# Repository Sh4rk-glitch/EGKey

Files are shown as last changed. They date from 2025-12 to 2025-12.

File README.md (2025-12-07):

# EGKey (ErgoKey)

A custom ergonomic keyboard PCB design using Choc-style hotswap sockets, a face-down Promicro footprint, and an optional OLED. This repository contains KiCad board sources, generated gerbers, mechanical DXF outlines, and footprint helper scripts driven by a YAML configuration.

---

# Files

## CAD
Inside `EGKey main file` there are many different files below is what is most important and how to get there: 
Starting off with the CAD files, the CAD is under `CAD files`. The main CAD file is `case. step`, if you want the other CAD files then click on `cases` and the rest are in there.
To see the outlines for the CAD go to `config.yaml` and then `output` and then `outlines`.

## PCBs
The PCBs are under `pcbs` then going to `ALL PCBS`. The main PCB file is `EGKeyMasterPCB`, if you wish to see the no routing and my previous attempts at routing then click on `EGKey-noRouting` and `EGKeyPCB-routingV2`.
The gerber file is under `pcbs` then click on the `EGKeyGerb` file, it's a zip file so it'll download as a zip.
Under `config.yaml` the footprint for the mounting hole is there under `footprints` and then its the only file under there.

## Firmware
To get to the firmware file, click on `firmware` which will be under `EGKey main file` and then inside `firmware` will be all the firmware writting for EGKey.

## Bill of Materials
  Part                                 Count                     Cost
- PCB Fab (With Shipping)	               1	                  $30.00 USD
- Arduino Pro Micro	                     1	                  $10.00 USD
- OLED Display	                         1	                   $4.00 USD
- Kailh Choc v2 Switches	               6 (58 Keys Total)	  $30.00 USD
- 1N4148 Diodes (SMD)	                   6 (58 Diodes Total)	 $2.00 USD
- Kailh Choc Hotswap Sockets	           6 (58 Sockets Total)	$10.00 USD
- Reset Switch (SMD, 4 Pin, Flat)	       1	                   $0.50 USD
- Mill Max Sockets & Pins	               1	                   $7.50 USD
- Medium Profile Controller Socket	     1	                   $0.50 USD
- Choc v1 Keycaps	                       1	                  $50-75 USD

Total: $140-160 USD

---
# Pictures:
## PCBs:


## CAD:


All images are located on my journal, at:
[https://blueprint.hackclub.com/projects/5019](url)

If you have any questions, email me at shouryamishra011@gmail.com

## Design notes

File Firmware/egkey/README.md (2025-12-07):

EGKey QMK scaffold
===================

This folder contains a minimal QMK keyboard scaffold for the EGKey PCB.

Important: This scaffold uses placeholder pin mappings. Replace `MATRIX_ROW_PINS` and
`MATRIX_COL_PINS` in `config.h` with the actual pins from your PCB before building.

Quick steps to build and flash (recommended: use WSL or QMK MSYS):

1. Copy this folder into your QMK firmware repo under `keyboards/egkey`:

   - `qmk_firmware/keyboards/egkey`

2. Install QMK build environment (see https://docs.qmk.fm)

3. From the qmk_firmware root (WSL / MSYS):

   ```powershell
   qmk compile -kb egkey -km default
   ```

4. To flash using QMK CLI (replace COM3 with your Pro Micro port):

   ```powershell
   qmk flash -kb egkey -km default -p COM3
   ```

Or use QMK Toolbox: build a `.hex` then open QMK Toolbox, put your Pro Micro into
bootloader (double-tap reset or short RST to GND), then load the hex and flash.

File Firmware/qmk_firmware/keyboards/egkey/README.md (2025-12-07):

EGKey QMK scaffold
===================

This folder contains a minimal QMK keyboard scaffold for the EGKey PCB.

Important: This scaffold uses conservative pin mappings to allow an initial
build. Verify `MATRIX_ROW_PINS` and `MATRIX_COL_PINS` in `config.h` against
your schematic and KiCad before using the board in production.

Quick steps to build and flash (recommended: use WSL or QMK MSYS):

1. From the qmk_firmware root (WSL / MSYS):

   ```bash
   qmk compile -kb egkey -km dm9records_ergoinu_layout_2025-12-07
   ```

2. To flash using QMK CLI (replace COM3 with your Pro Micro port):

   ```powershell
   qmk flash -kb egkey -km dm9records_ergoinu_layout_2025-12-07 -p COM3
   ```

Or use QMK Toolbox: build a `.hex` then open QMK Toolbox, put your Pro Micro into
bootloader (double-tap reset or short RST to GND), then load the hex and flash.

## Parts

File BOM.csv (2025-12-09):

Pro Micro (USB-C Version) - 5V/16MHz - Arduino-compatible ATmega32U4:
https://keeb.io/products/pro-micro-usb-c-version-5v-16mhz-arduino-compatible-atmega32u4
OLED Display:
https://kriscables.com/product/oled-display/
Kailh Box White Mechanical Keyboard Switches,3-Pin 45gf Clicky/Speed Typing/Gaming/Waterproof Switches(72Pcs,Kailh Box White):
https://www.amazon.com/Zjmehty-Mechanical-Keyboard-Switches-Waterproof/dp/B0CBPR6SVL?hvadid=648114561242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
1N4148 Diodes SMD (10 pcs):
https://www.aliexpress.us/item/3256806137153769.html?mp=1
Kailh Choc V1 Hot-swap Sockets (10 pcs):
https://holykeebs.com/products/kailh-choc-hotswap-sockets?variant=44532144079138
Reset Switch (SMD, 4 Pin, Flat):
https://42keebs.eu/shop/parts/components/reset-switch/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
Machine Sockets and pins:
https://typeractive.xyz/products/machine-sockets-and-pins?variant=45741664469223
Microcontroller Socket (Medium-profile, 40-pin):
https://42keebs.eu/shop/parts/components/microcontroller-socket-medium-profile/?attribute_pa_colour=black
CFX WoB Translucent Font Keycap Set:
https://keebd.com/en-us/products/cfx-wob-translucent-font-keycap-set

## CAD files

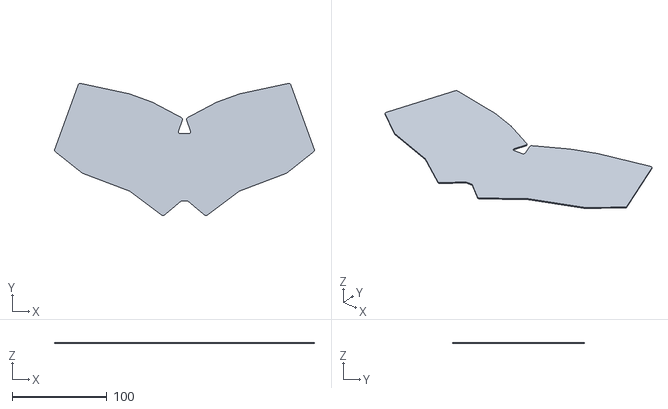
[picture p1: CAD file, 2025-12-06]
CAD Files/cases/xlBottom.stl
274.0 x 139.4 x 1.00

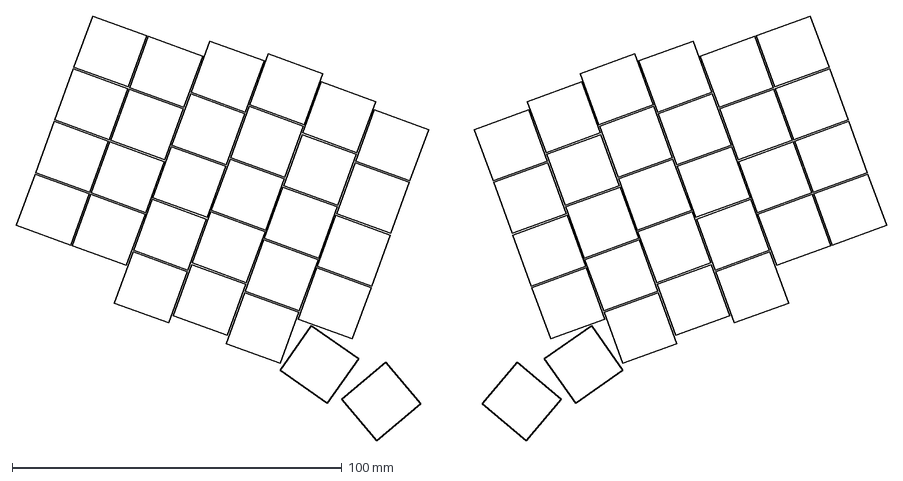
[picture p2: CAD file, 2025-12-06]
EGKey Main File/config.yaml/output/outlines/keys.dxf
263.8 x 128.8 mm

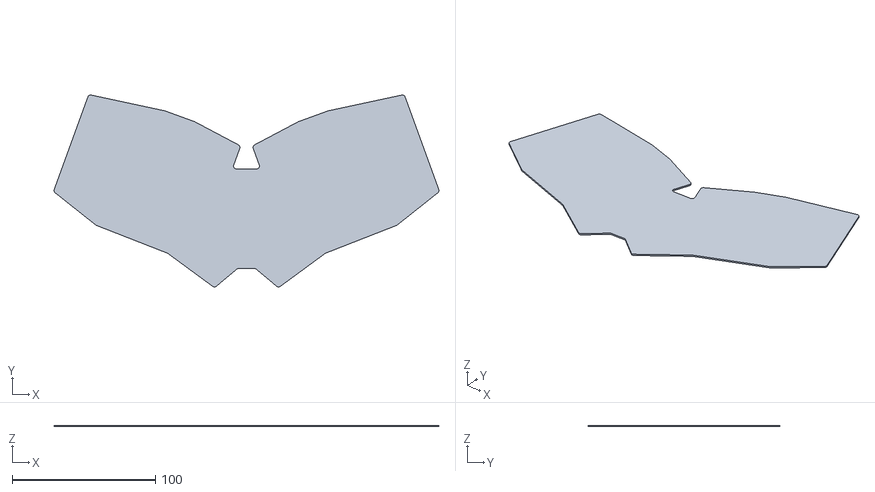
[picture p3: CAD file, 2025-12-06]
CAD Files/cases/bottom.stl
268.8 x 134.0 x 1.00

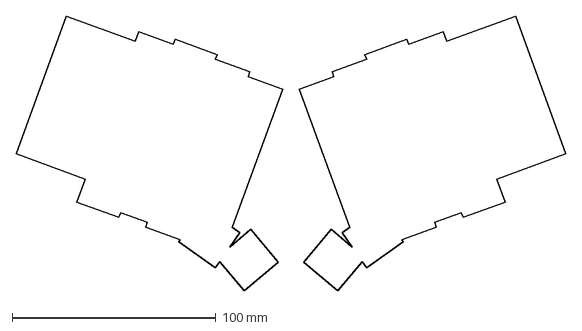
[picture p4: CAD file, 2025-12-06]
EGKey Main File/config.yaml/output/outlines/raw.dxf
269.6 x 134.8 mm

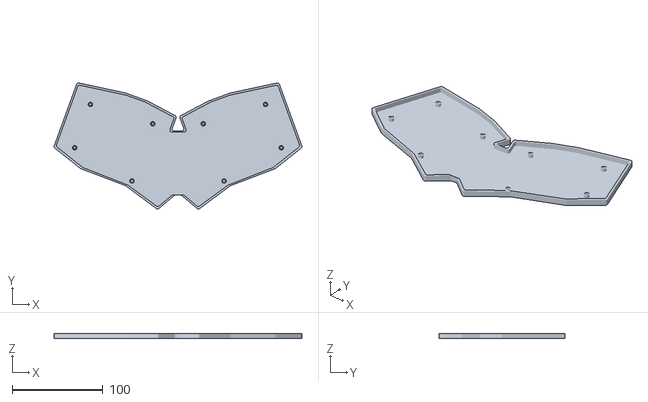
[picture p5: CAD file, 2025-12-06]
CAD Files/cases/case.stl
274.0 x 139.4 x 5.60

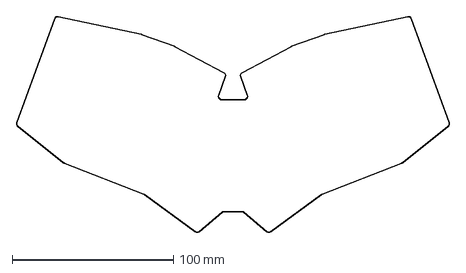
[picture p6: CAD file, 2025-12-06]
EGKey Main File/config.yaml/output/outlines/board.dxf
269.2 x 134.4 mm

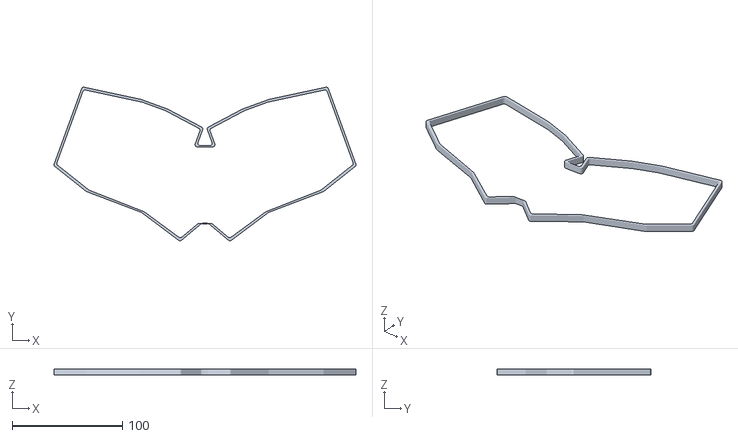
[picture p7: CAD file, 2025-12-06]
CAD Files/cases/wall.stl
274.0 x 139.4 x 5.60

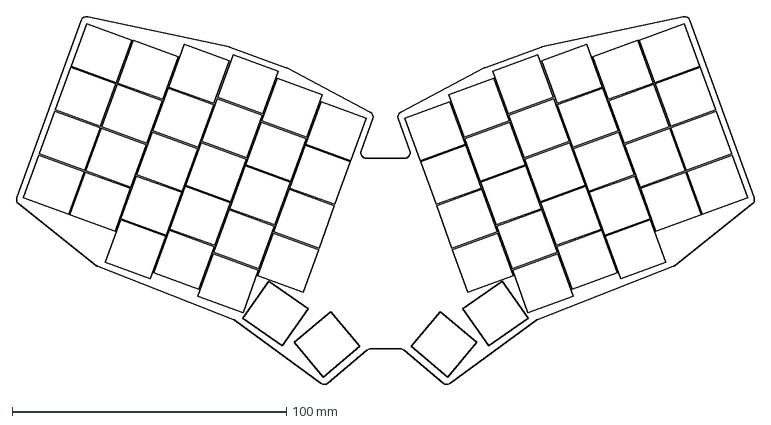
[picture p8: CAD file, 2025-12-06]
EGKey Main File/config.yaml/output/outlines/combo.dxf
269.2 x 134.4 mm

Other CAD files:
CAD Files/case.step

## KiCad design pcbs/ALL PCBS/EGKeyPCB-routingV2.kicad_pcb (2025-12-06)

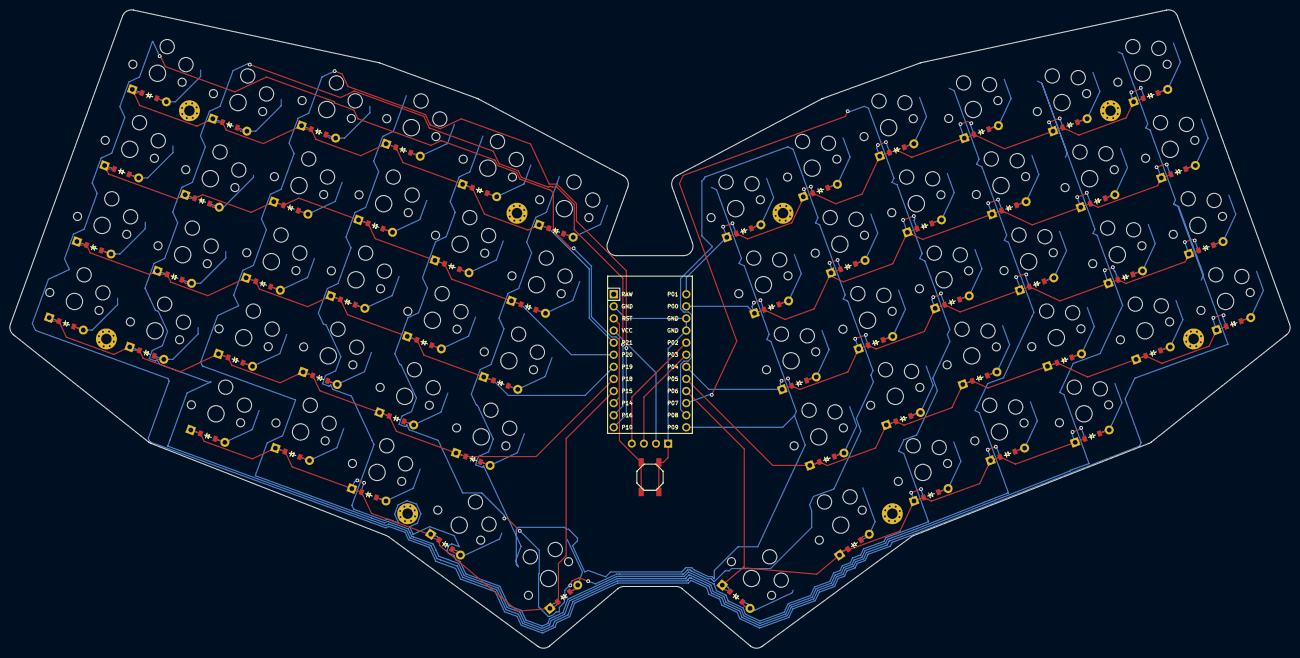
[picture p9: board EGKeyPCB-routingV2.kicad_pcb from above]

Board: 2 copper layers, 268.9 x 134.0 mm, 127 parts (0 on the bottom side), 79 nets.

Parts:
B1: SW_TACT_ALPS_SKQGABE010
D1, D2, D3, D4, D5, D6, D7, D8, D9, D10, D11, D12, D13, D14, D15, D16, D17, D18, D19, D20, D21, D22, D23, D24, D25, D26, D27, D28, D29, D30, D31, D32, D33, D34, D35, D36, D37, D38, D39, D40, D41, D42, D43, D44, D45, D46, D47, D48, D49, D50, D51, D52, D53, D54, D55, D56, D57, D58: ComboDiode
MCU1: ProMicro
OLED1: OLED; OLED_headers
S1, S2, S3, S4, S5, S6, S7, S8, S9, S10, S11, S12, S13, S14, S15, S16, S17, S18, S19, S20, S21, S22, S23, S24, S25, S26, S27, S28, S29, S30, S31, S32, S33, S34, S35, S36, S37, S38, S39, S40, S41, S42, S43, S44, S45, S46, S47, S48, S49, S50, S51, S52, S53, S54, S55, S56, S57, S58: PG1350
_1, _2, _3, _4, _5, _6, _7, _8: MountingHole_2.2mm_M2_Pad_Via

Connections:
GND: B1.1, MCU1.2, MCU1.15, MCU1.16, OLED1.1
P0: D32.1, D36.1, D41.1, D46.1, D51.1, D55.1, MCU1.14
P1: D33.1, D37.1, D42.1, D47.1, D52.1, D56.1, MCU1.13
P2: MCU1.17, OLED1.4
P3: MCU1.18, OLED1.3
P4: D31.1, D35.1, D40.1, D45.1, D50.1, D54.1, MCU1.19
P5: D30.1, D34.1, D39.1, D44.1, D49.1, D53.1, MCU1.20
P6: D38.1, D43.1, D48.1, D57.1, D58.1, MCU1.21
P7: MCU1.22, S15.1, S16.1, S17.1, S18.1, S19.1, S44.1, S45.1, S46.1, S47.1, S48.1
P8: MCU1.23, S20.1, S21.1, S22.1, S23.1, S28.1, S49.1, S50.1, S51.1, S52.1, S57.1
P9: MCU1.24, S24.1, S25.1, S26.1, S27.1, S29.1, S53.1, S54.1, S55.1, S56.1, S58.1
P10: MCU1.12, S10.1, S11.1, S12.1, S13.1, S14.1, S39.1, S40.1, S41.1, S42.1, S43.1
P14: MCU1.10, S1.1, S2.1, S3.1, S4.1, S30.1, S31.1, S32.1, S33.1
P15: D9.1, D14.1, D19.1, D28.1, D29.1, MCU1.9
P16: MCU1.11, S5.1, S6.1, S7.1, S8.1, S9.1, S34.1, S35.1, S36.1, S37.1, S38.1
P18: D1.1, D5.1, D10.1, D15.1, D20.1, D24.1, MCU1.8
P19: D2.1, D6.1, D11.1, D16.1, D21.1, D25.1, MCU1.7
P20: D3.1, D7.1, D12.1, D17.1, D22.1, D26.1, MCU1.6
P21: D4.1, D8.1, D13.1, D18.1, D23.1, D27.1, MCU1.5
RST: B1.2, MCU1.3
VCC: MCU1.4, OLED1.2
index_bottom: D20.2, S20.2
index_home: D21.2, S21.2
index_mod: D19.2, S19.2
index_num: D23.2, S23.2
index_top: D22.2, S22.2
inner_bottom: D24.2, S24.2
inner_home: D25.2, S25.2
inner_num: D27.2, S27.2
inner_top: D26.2, S26.2
layer_cluster: D28.2, S28.2
middle_bottom: D15.2, S15.2
middle_home: D16.2, S16.2
middle_mod: D14.2, S14.2
middle_num: D18.2, S18.2
middle_top: D17.2, S17.2
mirror_index_bottom: D49.2, S49.2
mirror_index_home: D50.2, S50.2
mirror_index_mod: D48.2, S48.2
mirror_index_num: D52.2, S52.2
mirror_index_top: D51.2, S51.2
mirror_inner_bottom: D53.2, S53.2
mirror_inner_home: D54.2, S54.2
mirror_inner_num: D56.2, S56.2
mirror_inner_top: D55.2, S55.2
mirror_layer_cluster: D57.2, S57.2
mirror_middle_bottom: D44.2, S44.2
mirror_middle_home: D45.2, S45.2
mirror_middle_mod: D43.2, S43.2
mirror_middle_num: D47.2, S47.2
mirror_middle_top: D46.2, S46.2
mirror_outer_bottom: D30.2, S30.2
mirror_outer_home: D31.2, S31.2
mirror_outer_num: D33.2, S33.2
mirror_outer_top: D32.2, S32.2
mirror_pinky_bottom: D34.2, S34.2
mirror_pinky_home: D35.2, S35.2
mirror_pinky_num: D37.2, S37.2
mirror_pinky_top: D36.2, S36.2
mirror_ring_bottom: D39.2, S39.2
mirror_ring_home: D40.2, S40.2
mirror_ring_mod: D38.2, S38.2
mirror_ring_num: D42.2, S42.2
mirror_ring_top: D41.2, S41.2
mirror_space_cluster: D58.2, S58.2
outer_bottom: D1.2, S1.2
outer_home: D2.2, S2.2
outer_num: D4.2, S4.2
outer_top: D3.2, S3.2
pinky_bottom: D5.2, S5.2
pinky_home: D6.2, S6.2
pinky_num: D8.2, S8.2
pinky_top: D7.2, S7.2
ring_bottom: D10.2, S10.2
ring_home: D11.2, S11.2
ring_mod: D9.2, S9.2
ring_num: D13.2, S13.2
ring_top: D12.2, S12.2
space_cluster: D29.2, S29.2

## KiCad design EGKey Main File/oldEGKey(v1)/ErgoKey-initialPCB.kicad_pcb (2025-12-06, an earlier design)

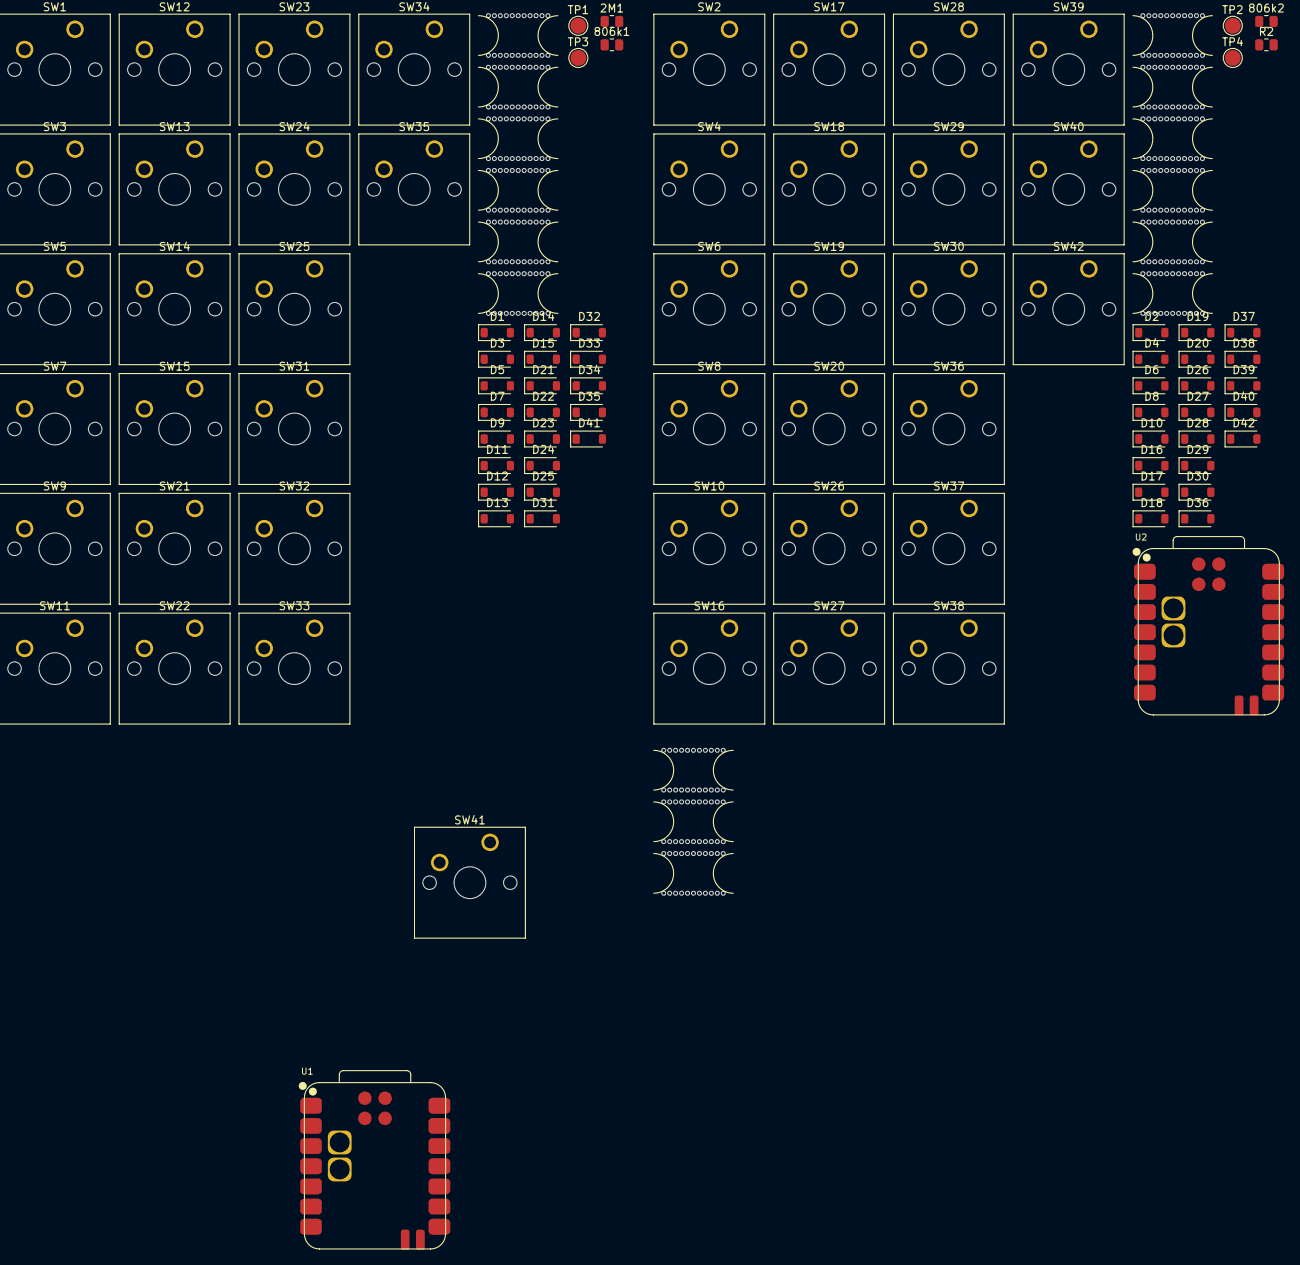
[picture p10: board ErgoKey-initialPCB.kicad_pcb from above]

Board: 2 copper layers, 109 parts (0 on the bottom side), 23 nets, no tracks yet.

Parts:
2M1, 806k2: R3; R_0805_2012Metric
806k1: R; R_0805_2012Metric
BO1, BO2, BO3: break off; mouse-bite-5mm-slot
D1, D2, D3, D4, D5, D6, D7, D8, D9, D10, D11, D12, D13, D14, D15, D16, D17, D18, D19, D20, D21, D22, D23, D24, D25, D26, D27, D28, D29, D30, D31, D32, D33, D34, D35, D36, D37, D38, D39, D40, D41, D42: D; D_SOD-123
H1, H2, H3, H4, H5, H6, H7, H8, H9, H10, H11, H12: mouse-bite-5mm-slot
R2: R; R_0805_2012Metric
SW1, SW2, SW3, SW4, SW5, SW6, SW7, SW8, SW9, SW10, SW11, SW12, SW13, SW14, SW15, SW16, SW17, SW18, SW19, SW20, SW21, SW22, SW23, SW24, SW25, SW26, SW27, SW28, SW29, SW30, SW31, SW32, SW33, SW34, SW35, SW36, SW37, SW38, SW39, SW40, SW41, SW42: SW_Push; SW_Cherry_MX_1.00u_PCB
TP1, TP2: bat; TestPoint_Pad_D2.0mm
TP3, TP4: GND; TestPoint_Pad_D2.0mm
U1, U2: XIAO-nRF52840-SMD; modified-XIAO-nRF52840-SMD

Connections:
/Left/BT_PIN: 806k1.2, U1.1 (P0.02_A0_D0)
/Left/COL0: SW11.1, SW21.1, SW31.1, U1.2 (P0.03_A1_D1)
/Left/COL1: SW12.1, SW22.1, SW32.1, U1.3 (P0.28_A2_D2)
/Left/COL2: SW13.1, SW23.1, SW33.1, U1.4 (P0.29_A3_D3)
/Left/COL3: SW14.1, SW24.1, SW34.1, U1.5 (P0.04_A4_D4_SDA)
/Left/COL4: SW15.1, SW25.1, SW35.1, SW41.1, U1.6 (P0.05_A5_D5_SCL)
/Left/ROW0: D3.1 (K), D5.1 (K), D7.1 (K), D9.1 (K), U1.11 (P1.15_D10_MOSI)
/Left/ROW1: D12.1 (K), D13.1 (K), D14.1 (K), D15.1 (K), U1.10 (P1.14_D9_MISO)
/Left/ROW2: D22.1 (K), D23.1 (K), D24.1 (K), D25.1 (K), U1.9 (P1.13_D8_SCK)
/Left/ROW3: D32.1 (K), D33.1 (K), D34.1 (K), D35.1 (K), U1.8 (P1.12_D7_RX)
/Left/VBAT: TP1.1, U1.15 (BAT)
/Right/BT_PIN: R2.2, U2.1 (P0.02_A0_D0)
/Right/COL0: SW16.1, SW26.1, SW36.1, U2.2 (P0.03_A1_D1)
/Right/COL1: SW17.1, SW27.1, SW37.1, U2.3 (P0.28_A2_D2)
/Right/COL2: SW18.1, SW28.1, SW38.1, U2.4 (P0.29_A3_D3)
/Right/COL3: SW19.1, SW29.1, SW39.1, U2.5 (P0.04_A4_D4_SDA)
/Right/COL4: SW20.1, SW30.1, SW40.1, SW42.1, U2.6 (P0.05_A5_D5_SCL)
/Right/ROW0: D4.1 (K), D6.1 (K), D8.1 (K), D10.1 (K), U2.11 (P1.15_D10_MOSI)
/Right/ROW1: D17.1 (K), D18.1 (K), D19.1 (K), D20.1 (K), U2.10 (P1.14_D9_MISO)
/Right/ROW2: D27.1 (K), D28.1 (K), D29.1 (K), D30.1 (K), U2.9 (P1.13_D8_SCK)
/Right/ROW3: D37.1 (K), D38.1 (K), D39.1 (K), D40.1 (K), U2.8 (P1.12_D7_RX)
/Right/VBAT: TP2.1, U2.15 (BAT)
GND: 806k2.2, TP3.1, TP4.1, U1.13 (GND), U1.16 (GND), U2.13 (GND), U2.16 (GND)

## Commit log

2025-12-06 Adding EGKey Main Files
    [EGKey-B_Cu.gbr, EGKey-B_Mask.gbr, EGKey-B_Paste.gbr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]
2025-12-06 Update README with project description
    Added project description and details about the PCB design.
2025-12-06 Updating Case CAD
2025-12-06 Add Bill of Materials to README
    Added a Bill of Materials section with detailed parts list and costs.
2025-12-07 Revise README structure and content
    Updated README to improve structure and clarity, including sections for CAD, PCBs, Firmware, and Fabrication Tips.
2025-12-07 Update README to clarify CAD files section
    Clarified the section about CAD files in the README.
2025-12-07 Upload Software and redo formatting for files
    [EGKey-B_Cu.gbr, EGKey-B_Mask.gbr, EGKey-B_Paste.gbr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]
2025-12-07 Add images for PCBs and CAD in README
    Added pictures of PCBs and CAD to the README.
2025-12-09 Adding PCB, CAD, and firmware to front page
    [EGKey-noRouting.kicad_pcb, EGKeyMasterPCB.kicad_pcb, EGKeyPCB-routingV2.kicad_pcb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]
2025-12-09 Adding BOM file
2025-12-09 Convert BOM to CSV format
    Converted BOM entries to CSV format with comma separation.
    [BOM.csv]
2025-12-09 Fix formatting and add spaces in BOM.csv
    [BOM.csv]
2025-12-09 Update BOM.csv to include headers and format URLs
    [BOM.csv]
2025-12-09 Remove duplicate entries in BOM.csv
    [BOM.csv]
2025-12-09 Add missing entries to BOM.csv
    Added missing BOM entries for components.
2025-12-09 Revise product entries and URLs in BOM.csv
    Updated product links and descriptions in BOM.csv.
    [BOM.csv]
2025-12-09 Update BOM.csv with new product links and formatting
    [BOM.csv]
2025-12-09 Revise BOM.csv with updated product information
    Updated BOM.csv with new product links and details.
    [BOM.csv]
